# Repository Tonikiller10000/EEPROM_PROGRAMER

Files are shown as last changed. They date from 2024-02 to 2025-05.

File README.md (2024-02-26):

# EEPROM_PROGRAMER

## Description:
This is an EEPROM programmer made to program the AT28C64 and AT28C256 EEPROMS with arduino. The programmer was made with the purpose to program the AT28C64 EEPROM for the [display register](https://github.com/Tonikiller10000/8BitProcessor/tree/main/DisplayRegister) of the 8 bit processor and the AT28C256 EEPROM for the [W65C02](https://github.com/Tonikiller10000/W65C02Computer) 8 bit computer.

### Version V1.0
The [EEPROM Programmer V1.0](https://github.com/Tonikiller10000/EEPROM_PROGRAMER/blob/main/EEPROM_PROGRAMER_V1.0/EEPROM_PROGRAMER_V1.0_Pictures/20230729_093718.jpg) has only 2 smd shift registers used with and arduino on the breadboard to set the eeprom address at programming. With this programmer, the shift register connections ware already made so you don`t have to place 2 shift registers on breadboard, but because of the pins placement, it needed to be connected with jumper wires.

### Version V2.0
The EEPROM Programmer V2.0 has 2 dip shift registers for an easy to build design. Also for an easier and faster way to program the EEPROMS, the ZIF socket was added witch also adds an cool design. This design needs dirrect connection of the 16 pins including 2 power pins, dirrectly to the arduino. 

<table>
  <tr>
    <td>

### Pinout
- EEPROM Data pins
    - D0-D7     : Data EEPROM IO pins
- Shift Register control pins
    - CLK       : Shift Register CLK pin
    - LATCH     : Shift Register Latch pin
    - OE        : Shift Register OE pin
    - DataIn    : Shift Register Serial Data In pin
- EEPROM control pins
    - WE        : EEPROM Write Enable pin
    - OE        : EEPROM Output Enable pin
    - GND       : arduino GND
    - VCC       : arduino 5V
    </td>
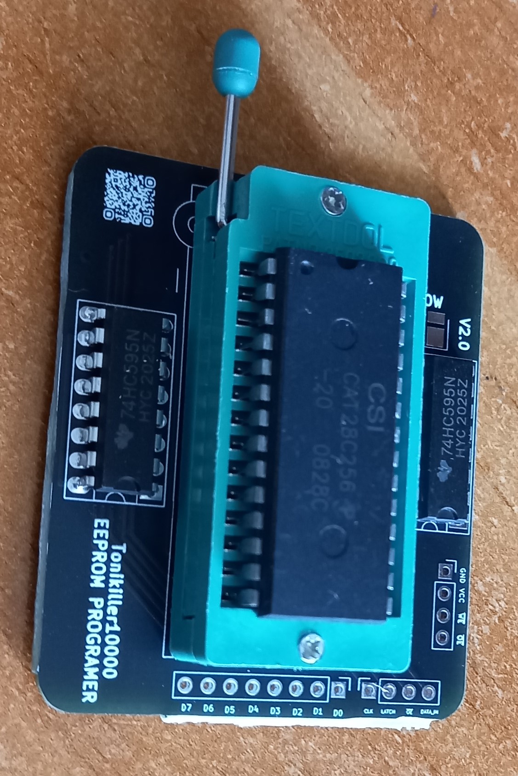
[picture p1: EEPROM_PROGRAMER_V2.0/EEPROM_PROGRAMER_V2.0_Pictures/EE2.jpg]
    <td></td>
  </tr>
</table>

### Version V3.0
This design is an plug and play version. It is an arduino shield, with some extra power, pins and 4 smd dip switches with one power switch and 8 modes to program the eeprom on the go, without the need of an computer.
<table>
  <tr>
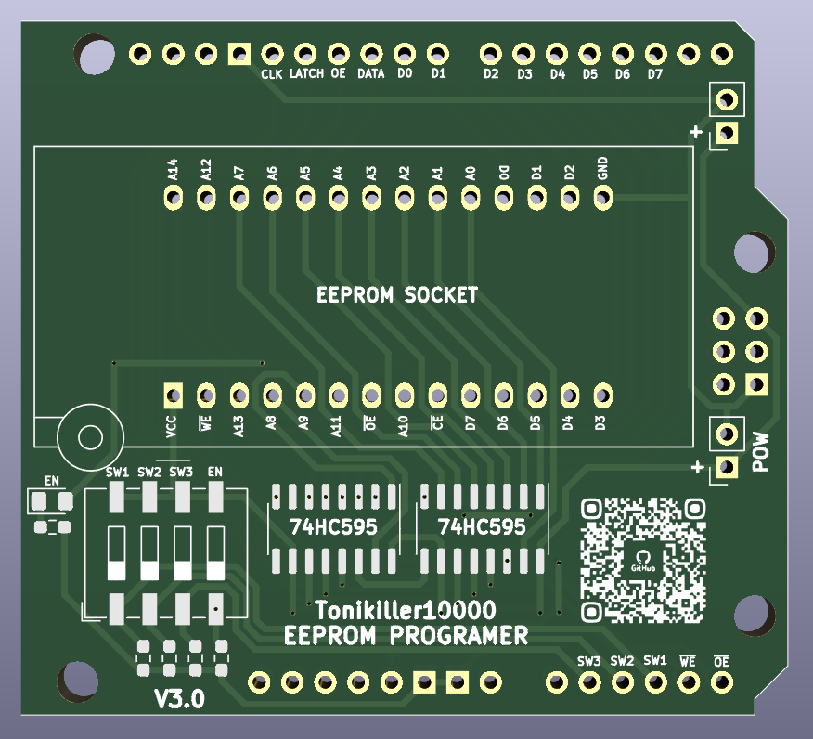
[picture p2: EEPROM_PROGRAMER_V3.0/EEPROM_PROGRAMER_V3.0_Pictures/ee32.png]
    <td></td>
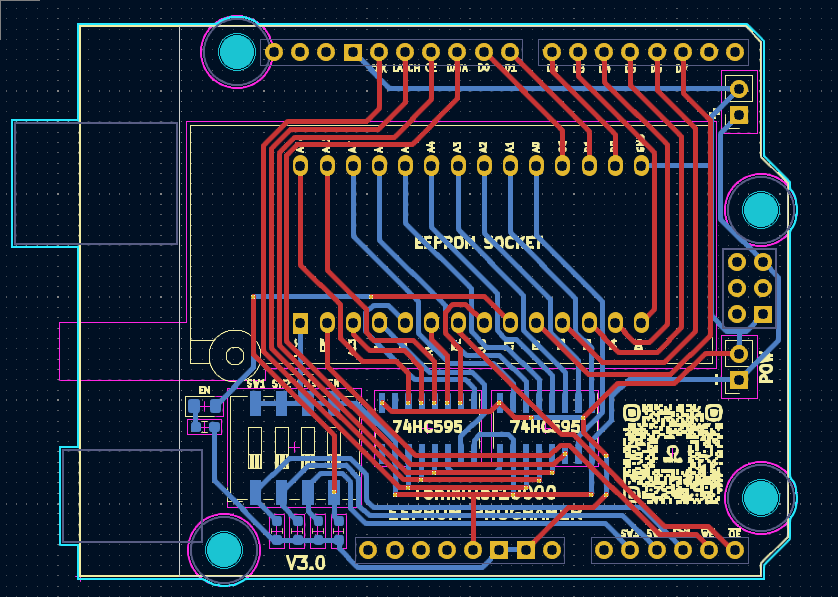
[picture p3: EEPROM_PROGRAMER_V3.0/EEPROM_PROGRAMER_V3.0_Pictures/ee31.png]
    <td></td>
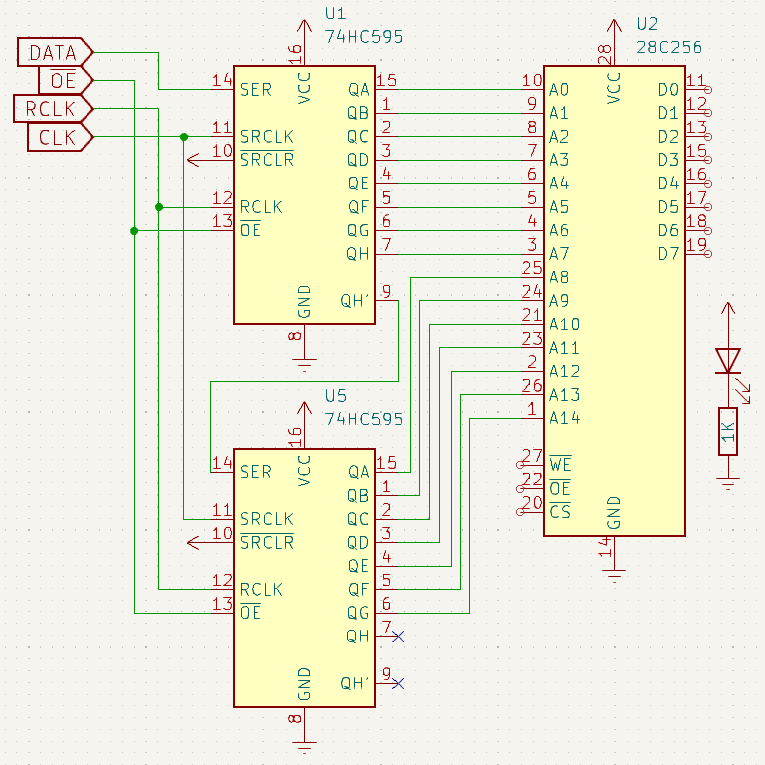
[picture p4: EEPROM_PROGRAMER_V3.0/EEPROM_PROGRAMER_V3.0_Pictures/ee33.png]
    <td></td>
  </tr>
</table>

## How to use:
- (*) make programs for the switches in the arduinoIDE (max 8);
- connect a battery;
- turn the power of the shield down;
- insert the EEPROM;
- set the switches for the data you want to program on it;
- press the reset button while turning the shield power on;   
- release the reset button and let the EEPROM be programed (may take a while).

## Programming:
[This](https://github.com/Tonikiller10000/EEPROM_PROGRAMER/blob/main/EEPROM_PROGRAMER_V2.0/EEPROM_PROGRAMER_V2.0.ino) code is made for the EEPROM V1.0 and V2.0. The software for the version 3.0 has permanent pins and  will be made when the board arrives.

## Links:
74HC595 datasheet (shift register): https://datasheetspdf.com/pdf-file/446162/ONSemiconductor/74HC595/1
AT28C256 datasheet (32K EEPROM): https://ww1.microchip.com/downloads/en/DeviceDoc/doc0006.pdf
AT28C64 datasheet (8K EEPROM): https://ww1.microchip.com/downloads/en/devicedoc/doc0001h.pdf

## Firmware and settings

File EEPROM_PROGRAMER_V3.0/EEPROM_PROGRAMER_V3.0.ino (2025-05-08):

int dataPin  = 10;  
int oePin    = 11;
int latchPin = 12;  
int clockPin = 13; 

int SW3 = A1;
int SW2 = A2;
int SW1 = A3;

int weRomPin = A4;   
int oeRomPin = A5; 
int RomDataPins[8]={2,3,4,5,6,7,8,9}; // ROM D7-D0 

int RomAddr  = 0;
int RomData  = 0;
int Mode = 0; 


//  \\//\\//\\//\\//\\// Stuff for the 8 bit DisplayRegister \\//\\//\\//\\//\\//
//A12-A8: MDLDL 
int DisplayDigitPosition = 0; 
int DisplayControlAddr[8] = {10,2,8,0,26,18,24,16}; 
int DisplayDigitsArray[16] = { 
  //E D DP C G B F A  
  0b11010111,
  0b00010100,
  0b11001101,
  0b01011101,
  0b00011110,
  0b01011011,
  0b11011011,
  0b00010101,
  0b11011111,
  0b01011111,
  0b10011111,
  0b11011010,
  0b11000011,
  0b11011100,
  0b11001011,
  0b10001011};







void DisplayRegisterProgram(){
 
    for(int i=0;i<256;i++){
      int nr=i;
      int n=3;
      do{
        WriteRomData(DisplayDigitsArray[nr%10], DisplayControlAddr[n]*256 + i);
        n--;
        nr/=10;
      }while(nr!=0);
      while(n>=0){
        WriteRomData(0b00000000, DisplayControlAddr[n]*256 + i);
        n--;
    }}

      for(int i=0;i<128;i++){
        int nr=i;
        int n=7;
        do{
          WriteRomData(DisplayDigitsArray[nr%10], DisplayControlAddr[n]*256 + i);
          n--;
          nr/=10;
        }while(nr!=0);
        while(n>=4){
          WriteRomData(0b00000000, DisplayControlAddr[n]*256 + i);
          n--;
        }
      }

      WriteRomData(DisplayDigitsArray[0], DisplayControlAddr[7]*256 + 128);
      WriteRomData(DisplayDigitsArray[0], DisplayControlAddr[6]*256 + 128);
      WriteRomData(DisplayDigitsArray[0], DisplayControlAddr[5]*256 + 128);
      WriteRomData(0b00001000, DisplayControlAddr[4]*256 + 128);

      for(int i=256;i>128;i--){
        int nr=256-i;
        int n=7;
        do{
          WriteRomData(DisplayDigitsArray[nr%10], DisplayControlAddr[n]*256 + i);
          n--;
          nr/=10;
        }while(nr!=0);
        while(n>=5){
          WriteRomData(0b00000000, DisplayControlAddr[n]*256 + i);//DisplayDigitsArray[0]
          n--;
        }

          WriteRomData(0b00001000, DisplayControlAddr[4]*256 + i);//0b00001000   minus
}}
//   //\\//\\//\\//\\//\\//\\//\\//\\//\\ Stuff for the 8 bit DisplayRegister  //\\//\\//\\//\\//\\//\\//\\//\\//\\



// Not Used yet
int BaseConverter(int Base1, int Base2, int nr1){
  int nr2=0, p=1;
  if(Base1<Base2)// from Base1 var value to Base10
    while(nr1){
      nr2=nr2 + p *(nr1 % 10);
      nr1/=10;
      p*=Base1;}
  return nr2;}


void SetRomAddr(int nr){
  digitalWrite(latchPin, LOW);
  shiftOut(dataPin, clockPin, MSBFIRST, nr/256); //Shift_Q0 == ROM_A0
  shiftOut(dataPin, clockPin, MSBFIRST, nr%256); //Shift_Q0 == ROM_A0
  digitalWrite(latchPin, HIGH);}

int ReadRomData(int addr){
  int nr=0;
  digitalWrite(oeRomPin, LOW);
  SetRomAddr(addr);
  for (int i=0;i<8;i++) pinMode(RomDataPins[i], INPUT);   
  delay(50);
  Serial.print("Read(");
  Serial.print(addr);
  Serial.print("): ");
  for (int i=0;i<8;i++){
    if(digitalRead(RomDataPins[i])){
      nr= 2*nr + 1;
      Serial.print(1);
    }
    else{
      nr= 2*nr + 0;
      Serial.print(0);
    }
  }
  Serial.print("-");
  Serial.println(nr);
  digitalWrite(oeRomPin, HIGH);
  delay(30);//delay
  return nr;}


void WriteRomData(int nr, int addr){
  int p = 128, nrc = nr;
  SetRomAddr(addr);
  for (int i=0;i<8;i++) pinMode(RomDataPins[i], OUTPUT);  
  Serial.print("Write(");
  Serial.print(addr);
  Serial.print("): ");
  for (int i=0;i<8;i++){
      if(nr>=p){
        Serial.print(1);
        digitalWrite(RomDataPins[i], 1);
        nr-=p;
      }
      else{
        Serial.print(0);
        digitalWrite(RomDataPins[i], 0);}
    p/=2;
  }
  Serial.print("-");
  Serial.println(nrc);
  digitalWrite(weRomPin, LOW);
  delay(80);
  digitalWrite(weRomPin, HIGH);
  delay(20);//delay
  }




















void setup() {
  pinMode(latchPin,  OUTPUT);
  pinMode(clockPin,  OUTPUT);
  pinMode(dataPin,   OUTPUT);
  pinMode(oePin,     OUTPUT);
  pinMode(weRomPin,  OUTPUT);
  pinMode(oeRomPin,  OUTPUT);
  pinMode(SW1,       INPUT);
  pinMode(SW2,       INPUT);
  pinMode(SW3,       INPUT);
  
  digitalWrite(weRomPin, HIGH);
  digitalWrite(oeRomPin, HIGH);
  digitalWrite(latchPin, LOW);
  digitalWrite(oePin,    LOW);
  Serial.begin(9600);

  Mode = digitalRead(SW1)*4 + digitalRead(SW1)*2 + digitalRead(SW1);


  WriteRomData(49, 20);
  delay(1000);
  ReadRomData(20);
  delay(1000);
  WriteRomData(5, 20);
  delay(1000);
  ReadRomData(20);
  delay(1000);

}

void loop() 
{

}

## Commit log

2023-09-13 EEPROM PROGRAMER V3.0
    I started the EEPROM_PROGRAMMER_V3.0 witch is an arduino uno shield version, and now I wodner if to use 74HC595 SMD to make it fit, because trouth hole version of the ic`s does not fit in the shield.
    Also I commented the code inside V2.0 .
    [EEPROM_PROGRAMER_V3.0.kicad_pcb, EEPROM_PROGRAMER_V3.0.kicad_sch]
2023-09-13 Reorder Folders
    [EEPROM_PROGRAMER_V3.0.kicad_pcb, EEPROM_PROGRAMER_V3.0.kicad_sch]
2023-09-21 Some changes at the V3.0 design
    [EEPROM_PROGRAMER_V3.0.kicad_pcb, EEPROM_PROGRAMER_V3.0.kicad_sch]
2024-01-14 V3.0 is ready to order
    [EEPROM_PROGRAMER_V3.0.kicad_pcb, EEPROM_PROGRAMER_V3.0.kicad_sch]
